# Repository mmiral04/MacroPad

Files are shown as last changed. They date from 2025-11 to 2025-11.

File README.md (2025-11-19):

# Introduction
Custom 3x3 MacroPad built with an ESP32. The purpose of the project is to experiment with PCB design and ESP32 programming. The hardware connects via bluetooth to a desktop app designed in Python.

The build is made up of a PCB, a metal frame and 9 MX switches. The electronic components needed are>

* ESP32 DevKit V1 board
* 1 resistor
* 1 LED
* 1 sideways 3-pin switch
* 1 switch
* 1 9V battery

# File structure

* The C code for the ESP32 is located inside the folder "EspCode". Upload this to ESP32 using Arduino IDE.
* The KiCad PCB design files are located inside the folder "KicadFiles". They have been developed in KiCad 9.
* The final PCB schematics, .step file for the metal frame, FreeCad project file for the metal frame and other files used in the design are located in the folder "DesignFiles".
* The code for the desktop app is located in the folder "Python" and "UI".

# Project build

The python app was built into an executable to execute on Windows startup using pyinstaller with the following command:

```

pyinstaller -F --noconsole --icon icon.ico Python\\main.py

```

The final build should look like:

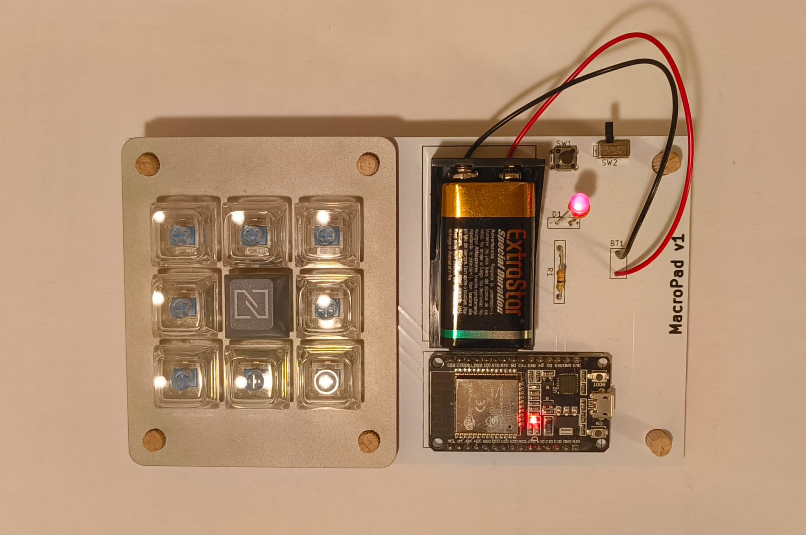
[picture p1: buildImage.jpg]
Build Image


# Usage

The desktop app has a GUI to connect to the macro pad via bluetooth and configure the macros. Currently the macros can be of three types:

* Keyboard shortcut (keys separated by +, e.g. "Ctrl + Shift + Esc" to open the Task Manager)
* Launch an application
* Launch a python script

All of the options can be customized with an icon or name.

The configuration of the macros is stored in the file "Python/config.json". When the application is closed it runs in the background and appears in the icon tray, where it can be fully exited.

The connection to the board via bluetooth has the MAC address of the board hardcoded in the python file "Python/main.py" and must be changed to the actual MAC address of the ESP32.

# Bugs and limitations

There are some limitations and bugs in the design:

* The 9V battery is not a viable power source as it drains the battery quickly. I am currently using the macro pad connected directly to the PC with USB.
* Connecting the macro pad via USB should not use bluetooth to connect, it would be better the use serial communication.
* If connecting the macro pad via USB with the PC, when another device is connected to the same computer via USB windows refreshes all USB devices and powers off the macro pad, leading to connection issues.

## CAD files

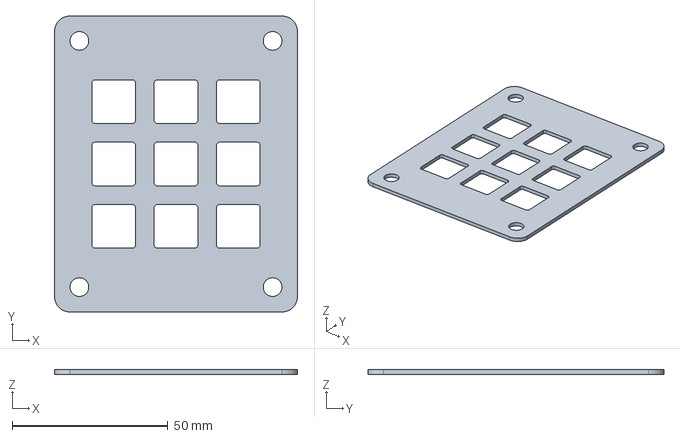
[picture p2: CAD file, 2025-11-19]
DesignFiles/MetalFrame_proyect.FCStd
78.0 x 95.0 x 1.50 mm

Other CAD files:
DesignFiles/MetalFrame.step

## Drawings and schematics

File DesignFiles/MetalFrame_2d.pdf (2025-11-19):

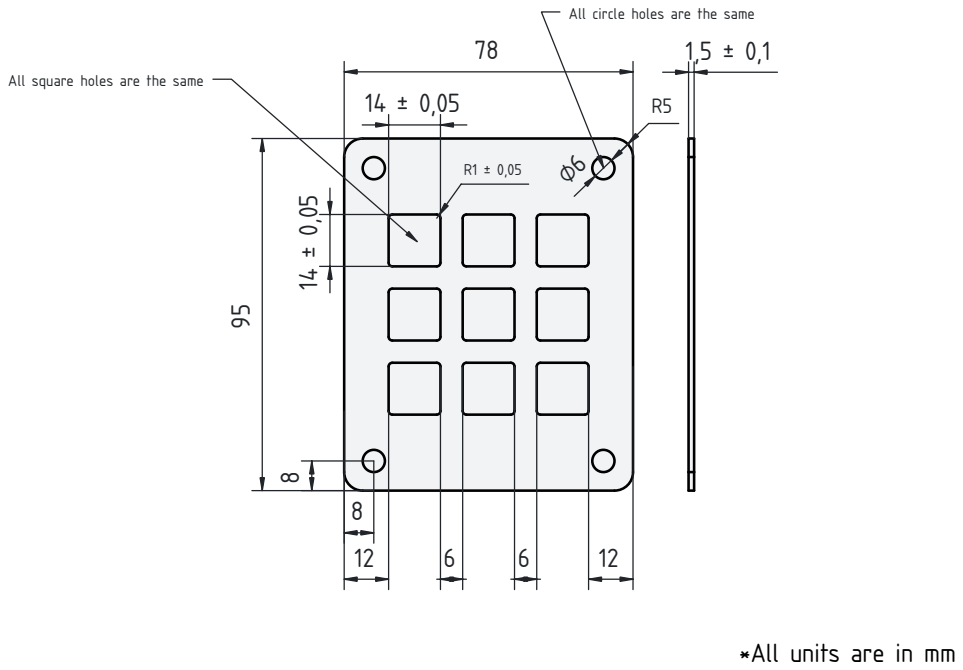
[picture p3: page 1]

All circle holes are the same

All square holes are the same

*All units are in mm

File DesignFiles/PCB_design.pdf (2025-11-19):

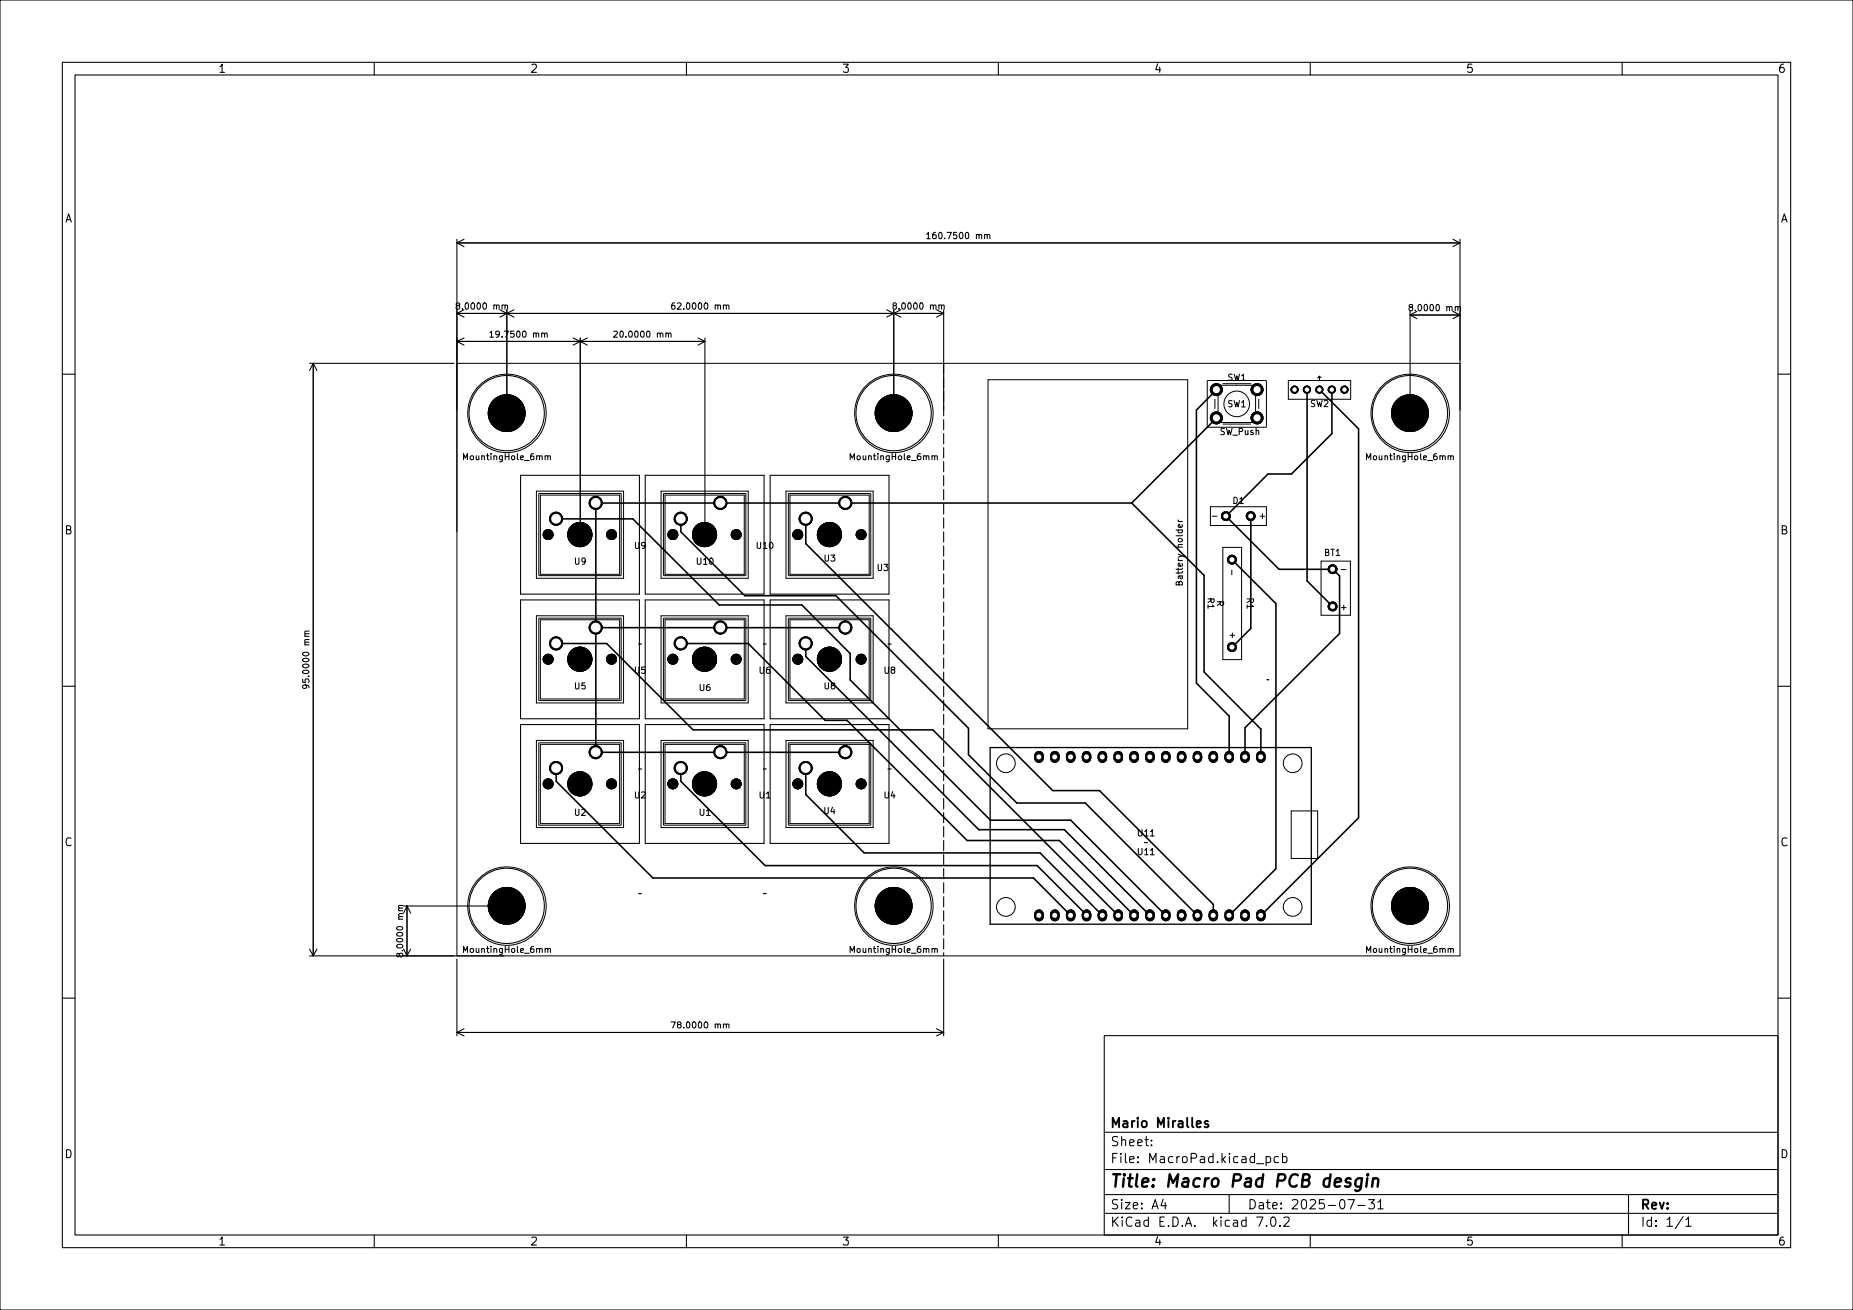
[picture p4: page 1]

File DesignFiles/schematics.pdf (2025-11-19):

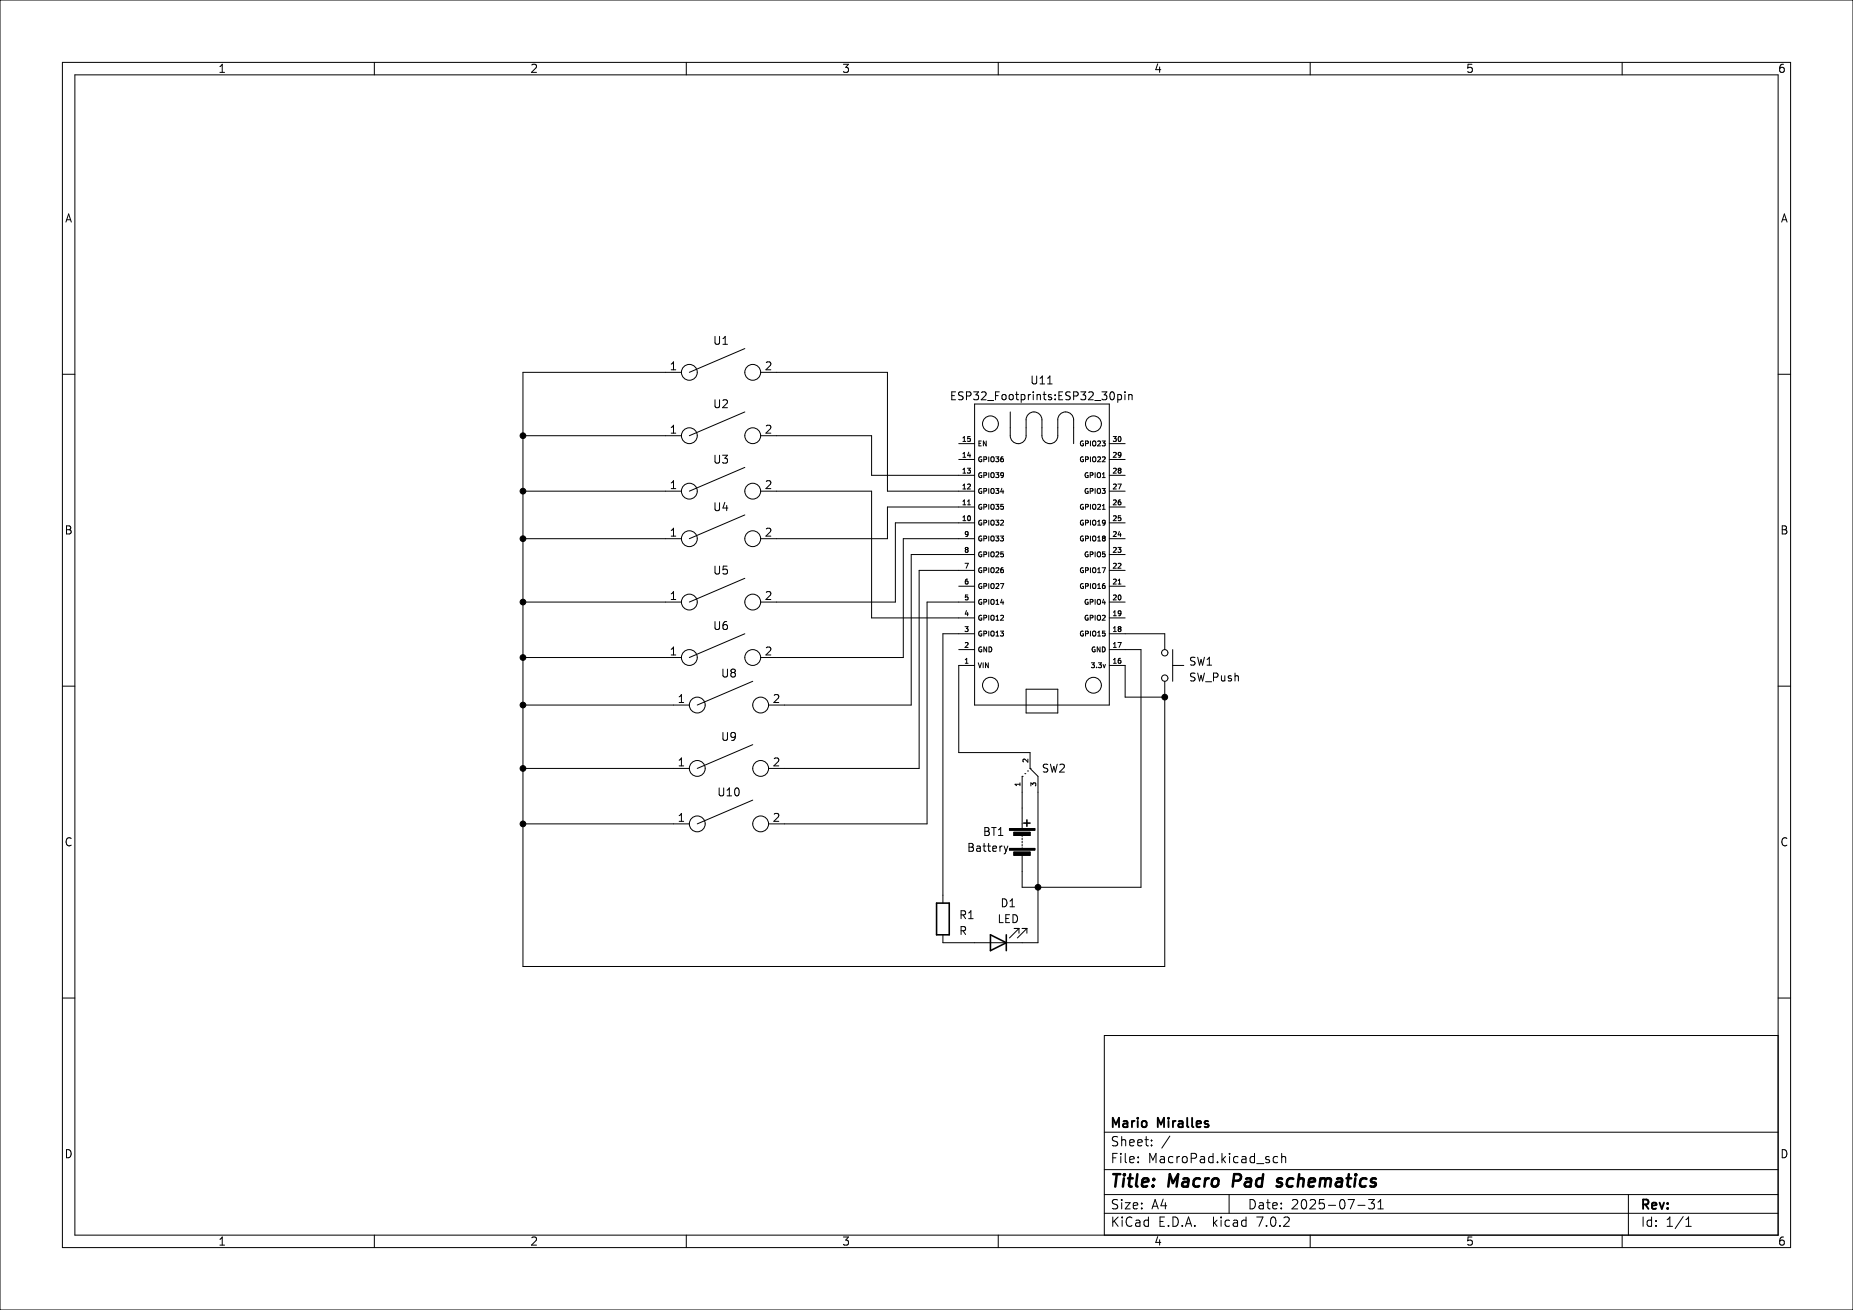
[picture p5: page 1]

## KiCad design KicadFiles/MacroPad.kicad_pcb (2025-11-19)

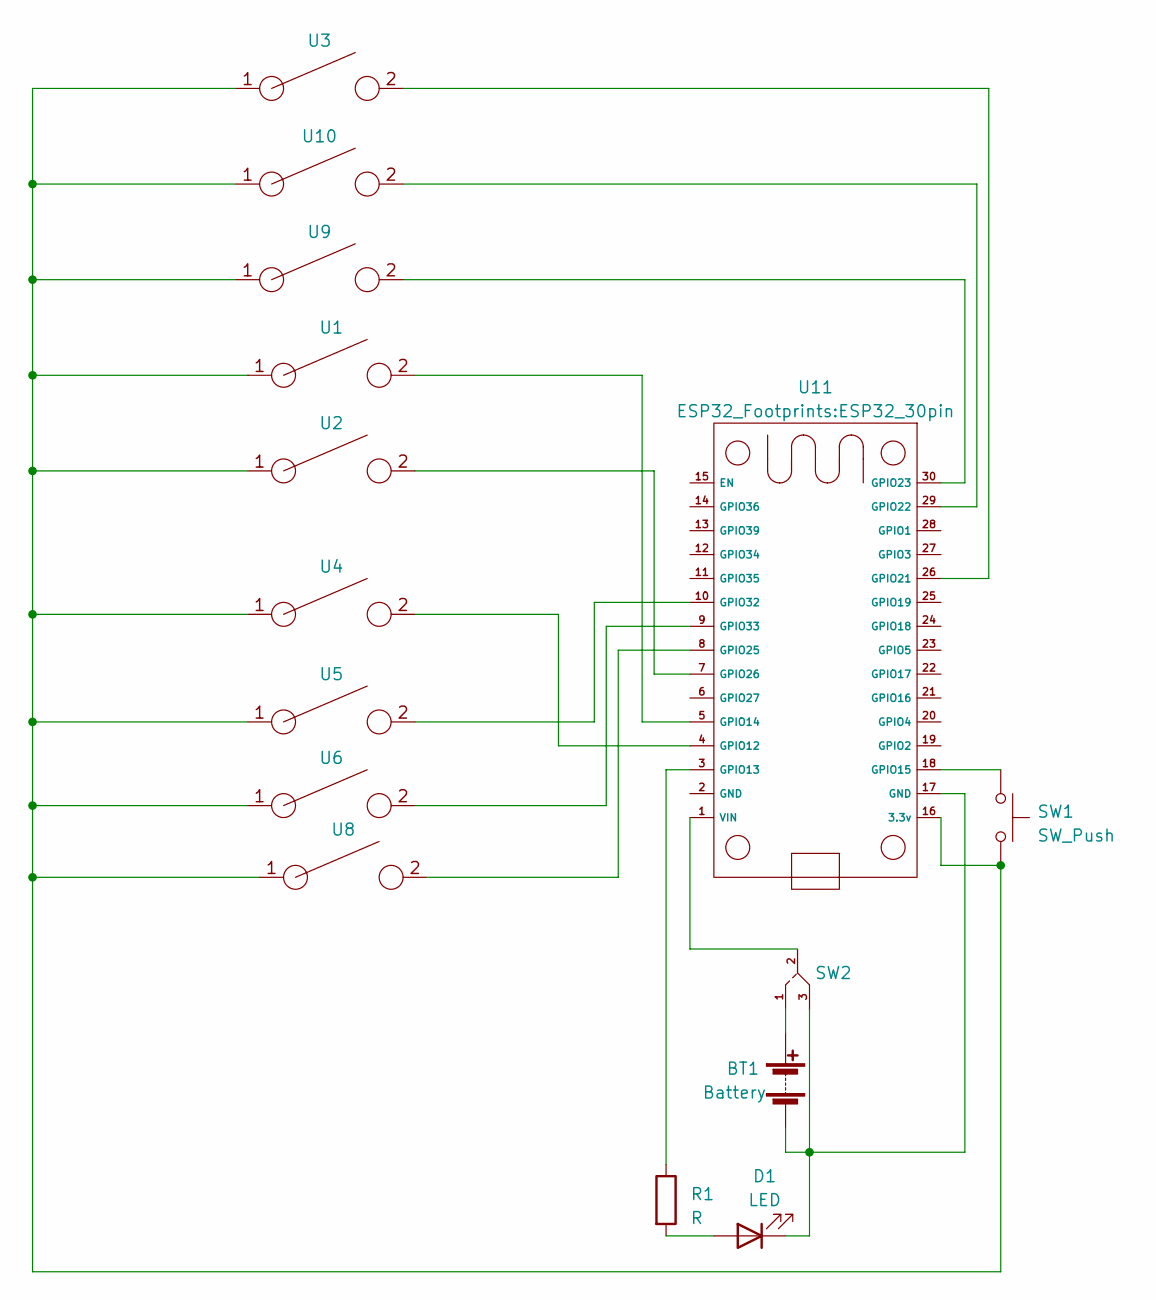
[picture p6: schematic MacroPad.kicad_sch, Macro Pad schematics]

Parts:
BT1: Battery; Battery holder
D1: LED; LED_holes
R1: R; Resistor_holes
SW1: SW_Push; SW_PUSH_6mm_H5mm
SW2: Switch conmutador
U1, U2, U3, U4, U5, U6, U8, U9, U10: SW_Cherry_MX_1.00u_PCB
U11: ESP32_30pin

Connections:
unnamed: BT1.1 (+), SW2.1
unnamed: BT1.2 (-), D1.1 (K), SW2.3, U11.17 (GND)
unnamed: D1.2 (A), R1.2
unnamed: SW1.2, U1.1, U2.1, U3.1, U4.1, U5.1, U6.1, U8.1, U9.1, U10.1, U11.16 (3.3v)
unnamed: U4.2, U11.4 (GPIO12)
unnamed: R1.1, U11.3 (GPIO13)
unnamed: U1.2, U11.5 (GPIO14)
unnamed: SW1.1, U11.18 (GPIO15)
unnamed: U3.2, U11.26 (GPIO21)
unnamed: U10.2, U11.29 (GPIO22)
unnamed: U9.2, U11.30 (GPIO23)
unnamed: U8.2, U11.8 (GPIO25)
unnamed: U2.2, U11.7 (GPIO26)
unnamed: U5.2, U11.10 (GPIO32)
unnamed: U6.2, U11.9 (GPIO33)
unnamed: SW2.2, U11.1 (VIN)

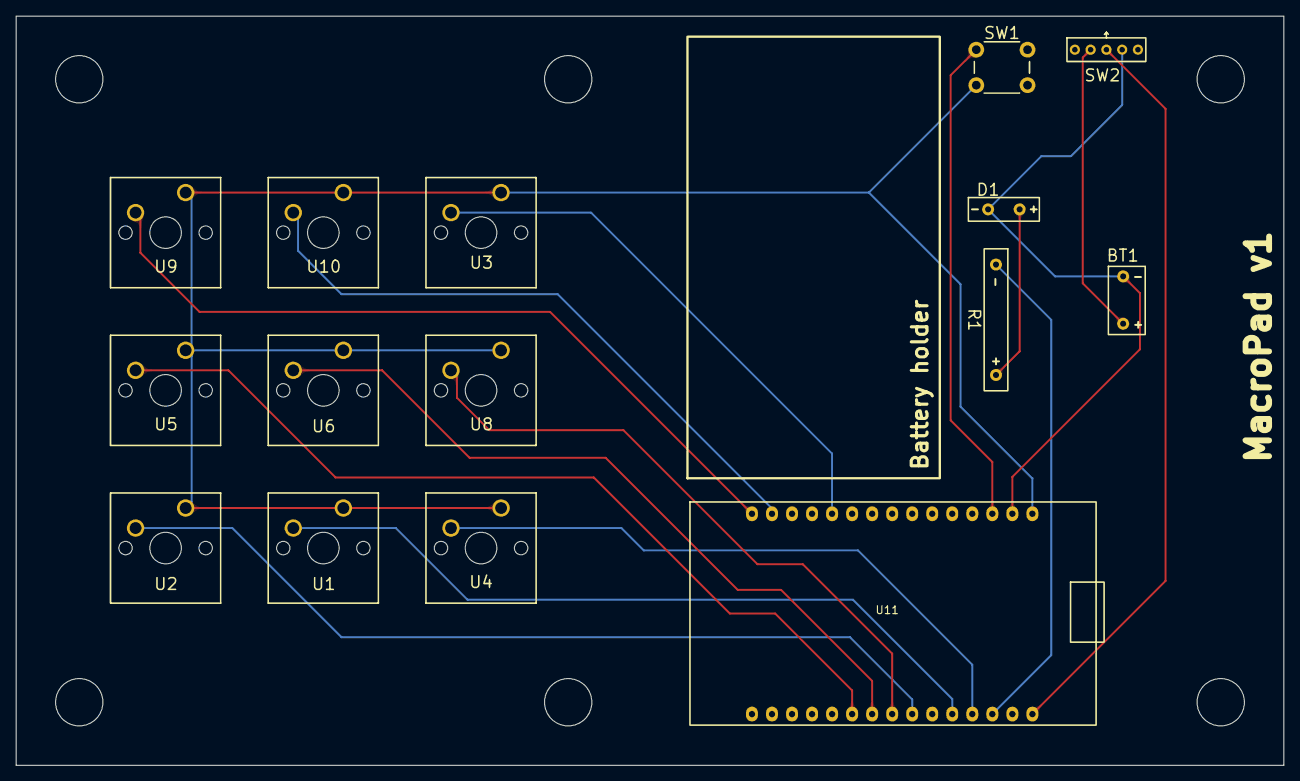
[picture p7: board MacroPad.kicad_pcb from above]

Board: 2 copper layers, 160.8 x 95.0 mm, 15 parts (0 on the bottom side), 16 nets.

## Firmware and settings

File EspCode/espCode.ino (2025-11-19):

#include "BluetoothSerial.h"
#include "esp_task_wdt.h"
#include "esp_err.h"


#if !defined(CONFIG_BT_ENABLED) || !defined(CONFIG_BLUEDROID_ENABLED)
#error Bluetooth is not enabled! Please run `make menuconfig` to and enable it
#endif


void print_wakeup_reason() {
  esp_sleep_wakeup_cause_t wakeup_reason;

  wakeup_reason = esp_sleep_get_wakeup_cause();

  switch (wakeup_reason) {
    case ESP_SLEEP_WAKEUP_EXT0:     Serial.println("Wakeup caused by external signal using RTC_IO"); break;
    case ESP_SLEEP_WAKEUP_EXT1:     Serial.println("Wakeup caused by external signal using RTC_CNTL"); break;
    case ESP_SLEEP_WAKEUP_TIMER:    Serial.println("Wakeup caused by timer"); break;
    case ESP_SLEEP_WAKEUP_TOUCHPAD: Serial.println("Wakeup caused by touchpad"); break;
    case ESP_SLEEP_WAKEUP_ULP:      Serial.println("Wakeup caused by ULP program"); break;
    default:                        Serial.printf("Wakeup was not caused by deep sleep: %d\n", wakeup_reason); break;
  }
}

String msg;
RTC_DATA_ATTR BluetoothSerial SerialBT;

// Pin numbers
#define N_BUTTONS 9
const int button_pin[N_BUTTONS] = {23, 22, 21, 33, 32, 25, 14, 26, 12};
const int disconnect_pin = 15;
const int led_pin = 13;

bool disconnect_flag;

void connectionProtocol(){
   bool connected = false;
   int state = LOW;
   while (!connected){
      digitalWrite(led_pin, (state == LOW ? HIGH : LOW));
      state = (state == LOW ? HIGH : LOW);
      if (SerialBT.available()){
         msg = "";
         readSerialPort();
         if (msg == "begin connection"){
            SerialBT.print("accept connection");
            SerialBT.flush();
            connected = true;
            Serial.println("Connection stablished");
            digitalWrite(led_pin, LOW);
         }
      }
      delay(1000);
   }
}

void disconnect(){
   digitalWrite(led_pin, HIGH);
   delay(2000);
   digitalWrite(led_pin, LOW);
   esp_light_sleep_start();
   print_wakeup_reason();
   digitalWrite(led_pin, HIGH);
   delay(2000);
   digitalWrite(led_pin, LOW);

}


void checkDisconnect() {
   msg = "";
   readSerialPort();
   if (msg == "disconnected"){
         disconnect_flag = true;
         Serial.println("Disconnected");
         disconnect();
   }
}



void setup() {
   disconnect_flag = false;

   Serial.begin(115200);
   SerialBT.begin("MacroPad"); //Bluetooth device name
   Serial.println("MacroPad device started, now you can pair it!");

   // initialize pins
   for (int i = 0; i < N_BUTTONS; i++){
      pinMode(button_pin[i], INPUT_PULLDOWN);
   }

   pinMode(disconnect_pin, INPUT_PULLDOWN);

   pinMode(led_pin, OUTPUT);

   esp_sleep_enable_ext0_wakeup(GPIO_NUM_15, 1);
   connectionProtocol();
}



void loop(){
   if (disconnect_flag) {
      ESP.restart();
   }

   // read buttons
   int button_state;
   int count = 0;
   for (int i = 0; i < N_BUTTONS; i++){
      button_state = digitalRead(button_pin[i]);
      if (button_state == HIGH){
         char strBuf[7];
         sprintf(strBuf, "Boton %d", i + 1);
         SerialBT.print(strBuf);
         Serial.println(strBuf);
         SerialBT.flush();
         delay(200);
         break;
      }
   }

   button_state = digitalRead(disconnect_pin);
   if (button_state == HIGH) {
      SerialBT.print("disconnect");
      SerialBT.flush();
      Serial.println("Disconnect pressed");
      disconnect();
      ESP.restart();
   }


   checkDisconnect();
}

void readSerialPort(){
   while (SerialBT.available()) {
      delay(10); 
      if (SerialBT.available() > 0) {
            char c = SerialBT.read();  //gets one byte from serial buffer
            msg += c; //makes the string readString
      }
   }
   SerialBT.flush();
}
